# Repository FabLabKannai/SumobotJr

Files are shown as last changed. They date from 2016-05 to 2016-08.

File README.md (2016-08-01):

# Sumobot Jr
Sumobot Jr is open source robot car kit. <br/>
original https://github.com/makenai/sumobot-jr <br/>

## Arduino version
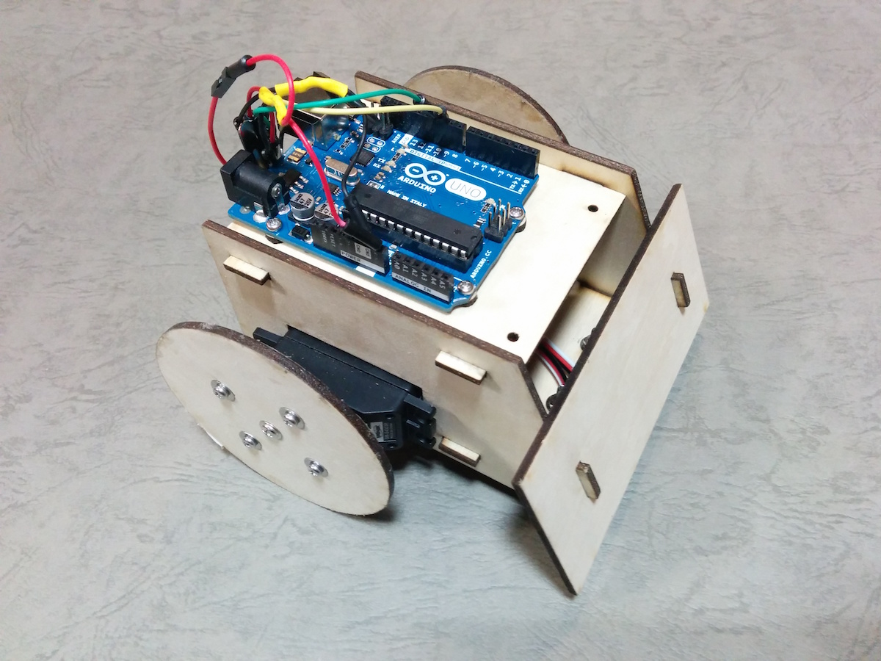
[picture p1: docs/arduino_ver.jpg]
 <br/>
Video [Sumobot Jr](https://www.youtube.com/watch?v=96kZ15I-gVY) <br/>

## Raspberry Pi version
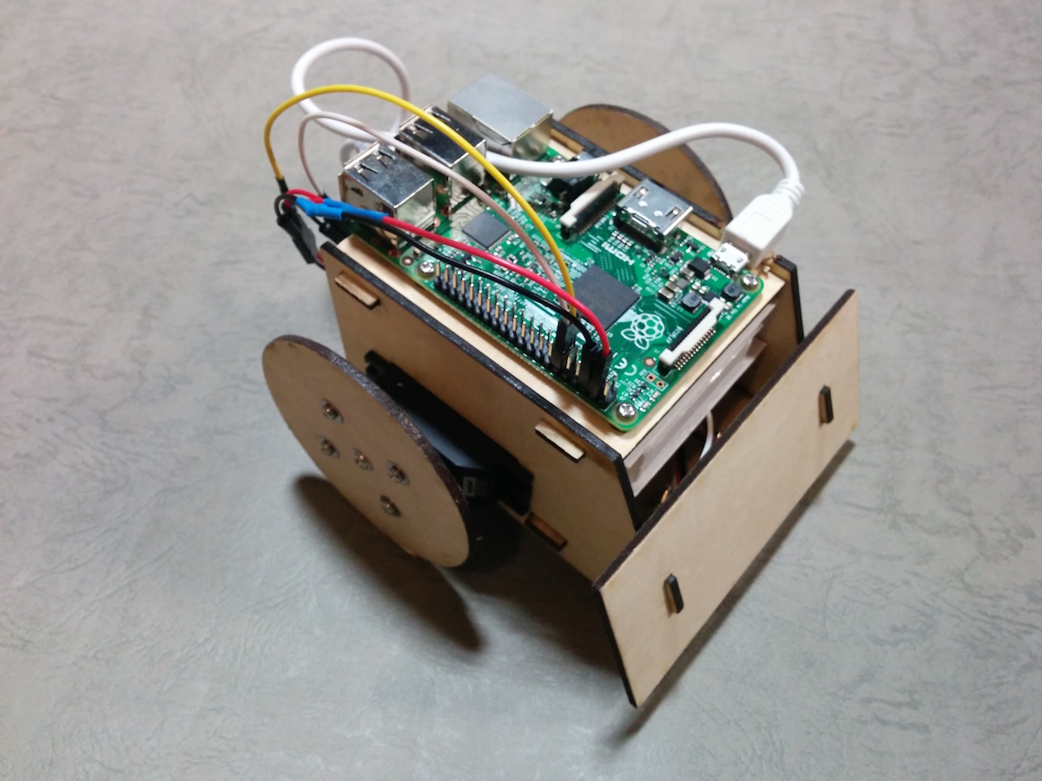
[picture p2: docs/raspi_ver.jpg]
 <br/>
Video [Sumobot with Raspberry Pi](https://www.youtube.com/watch?v=J9WRliGs7vI) <br/>

### Laser Cutter
- Body : SumbotJr 3mm

### 3D Printer
- BallCaster

### Arduino Skech
- sumobot web daemon<br/>
  web app to control Sumobot <br/>
- sumobot turn <br/>
  reft turn <-> stop <-> right turn <br/>
- sumobot command <br/>
  command specify forward, backward or etc
- servo class <br/>
  test using Servo class <br/>
- servo command <br/>
  command to specify the rotation direction and speed <br/>
- servo digitalwrite <br/>
  test using using digitalWrite <br/>
- servo fade <br/>
  clockwide <-> stop <-> anticlockwide <br/>

### Raspberry Pi Prgaram
- Sumobot web <br/>
  Web app to control Sumobot <br/>
- Sumobot Wii <br/>
  Sumobot controlled by Wii Remote <br/>
- Sumobot Scrach <br/>
  Sumobot controlled by Scrach <br/>
- sumobot turn <br/>
  reft turn <-> stop <-> right turn <br/>
- sumobot command <br/>
  command specify forward, backward or etc <br/>
- [WiringPi Servo](https://github.com/FabLabKannai/RaspiStudy/tree/master/4_python/sample/wiringpi_servo) <br/>
  test for Continuous Rotation Servo <br/> 
   
### Docs
- Parts
- Assembly

### Blog (Japanese)
http://android.ohwada.jp/archives/6714

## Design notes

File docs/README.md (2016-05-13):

# Docs - Sumobot Jr

### Arduino version
[see Arduino version](https://github.com/FabLabKannai/SumobotJr/tree/master/docs/arduino/) <br/>
 <br/>

### Raspberry Pi version
[see Raspberry Pi version](https://github.com/FabLabKannai/SumobotJr/tree/master/docs/raspi/) <br>
 <br/>

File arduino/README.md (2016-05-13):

# Arduino Skech - Sumobot Jr

 <br/>

## Skechs
- sumobot turn <br/>
  reft turn <-> stop <-> right turn <br/>
  Video [Sumobot Jr](https://www.youtube.com/watch?v=96kZ15I-gVY) <br/>
- sumobot command <br/>
  command specify forward, backward or etc
- servo class <br/>
  test using Servo class <br/>
- servo command <br/>
  command to specify the rotation direction and speed <br/>
- servo digitalwrite <br/>
  test using digitalWrite <br/>
- servo fade <br/>
  clockwide <-> stop <-> anticlockwide <br/>

### blog (Japanese)
http://android.ohwada.jp/archives/6674

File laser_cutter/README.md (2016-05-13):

# Laser Cutter - Sumobot Jr

- Body : SumbotJr 3mm <br/>
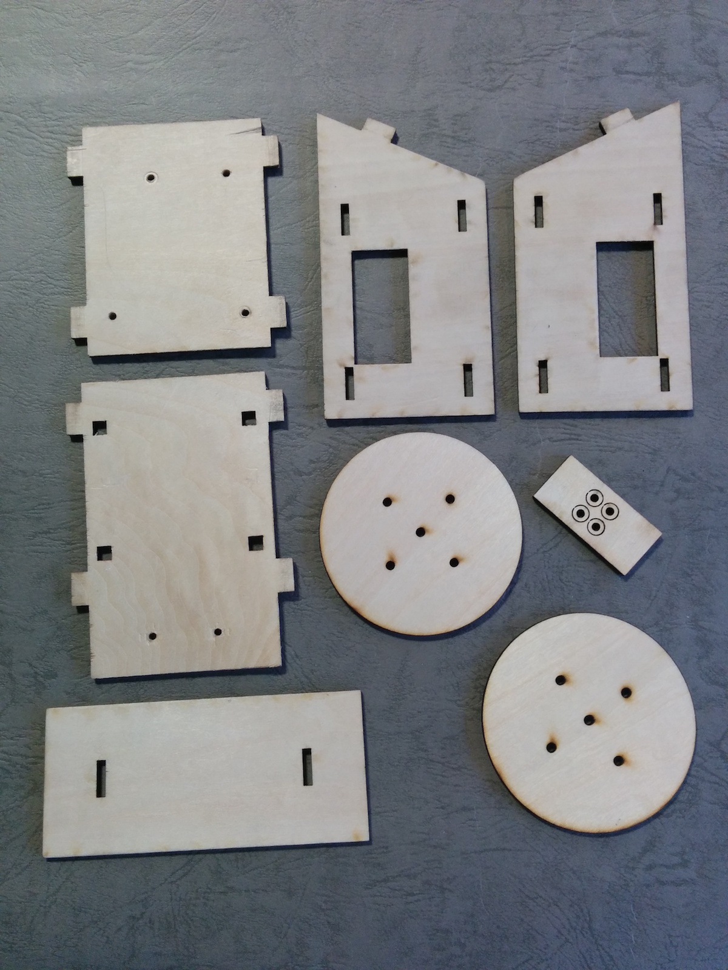
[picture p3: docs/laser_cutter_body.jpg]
 <br/>

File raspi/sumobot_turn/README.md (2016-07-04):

# sumobot turn - RasPi Program

Test for Sumobot using  continuous rotation servos <br/>
 <br/>
Video [Sumobot with Raspberry Pi](https://www.youtube.com/watch?v=J9WRliGs7vI) <br/>

## Program
- sumobot turn <br/>
Sumobot run immediately, when the program is started. <br/>
- sumobot turn check <br/>
Program starts, and it checks the state of the P13(GPIO 27). <br/>
Sumobot run, if pin is high. <br/>
Program stop, and Sumobot is stopped, if pin is low. <br/>

### Behavior
clockwide <-> stop <-> anticlockwide <br/>

### Install
> $ cd /tmp<br/>
$ git clone https://github.com/FabLabKannai/SumobotJr.git <br/>
$ mkdir ~/sumobot/ <br/>
$ cp SumobotJr/raspi/sumobot_turn/sumobot_turn_check.py ~/sumobot/ <br/>

### Start Automatically 1
Set to start this program, when the power is turned on. <br/>
Change /etc/rc.local <br/>
Add one line before "exit 0" <br/>
> $ sudo cp -p /etc/rc.local /etc/rc.local.orig <br/>
$ sudo nano /etc/rc.local <br/>
... <br/>
\# add <br/>
python /home/pi/sumobot/sumobot_turn_check.py <br/>
exit 0  <br/>

### Start Automatically 2
Alternative to change /etc/rc.local <br/>
> $ cd /tmp/SumobotJr/raspi/sumobot_turn/ <br/>
$ sudo cp -p /etc/rc.local /etc/rc.local.orig <br/>
$ sudo cp -f rc.local.sumobot_turn /etc/rc.local <br/>
$ sudo chmod 755 /etc/rc.local <br/>

### Quit to start automatically
Revert to the original /etc/rc.local
> $ sudo cp /etc/rc.local.orig /etc/rc.local

### Hardwear setup
Put a 10k resistor between P13(GPIO 27) and P17(3.3V).  <br/>
Sumobot will run endless. <br/>
Sumobot will be stopped, when connect to P14(GND) in place of the P17(3.3v).   <br/>
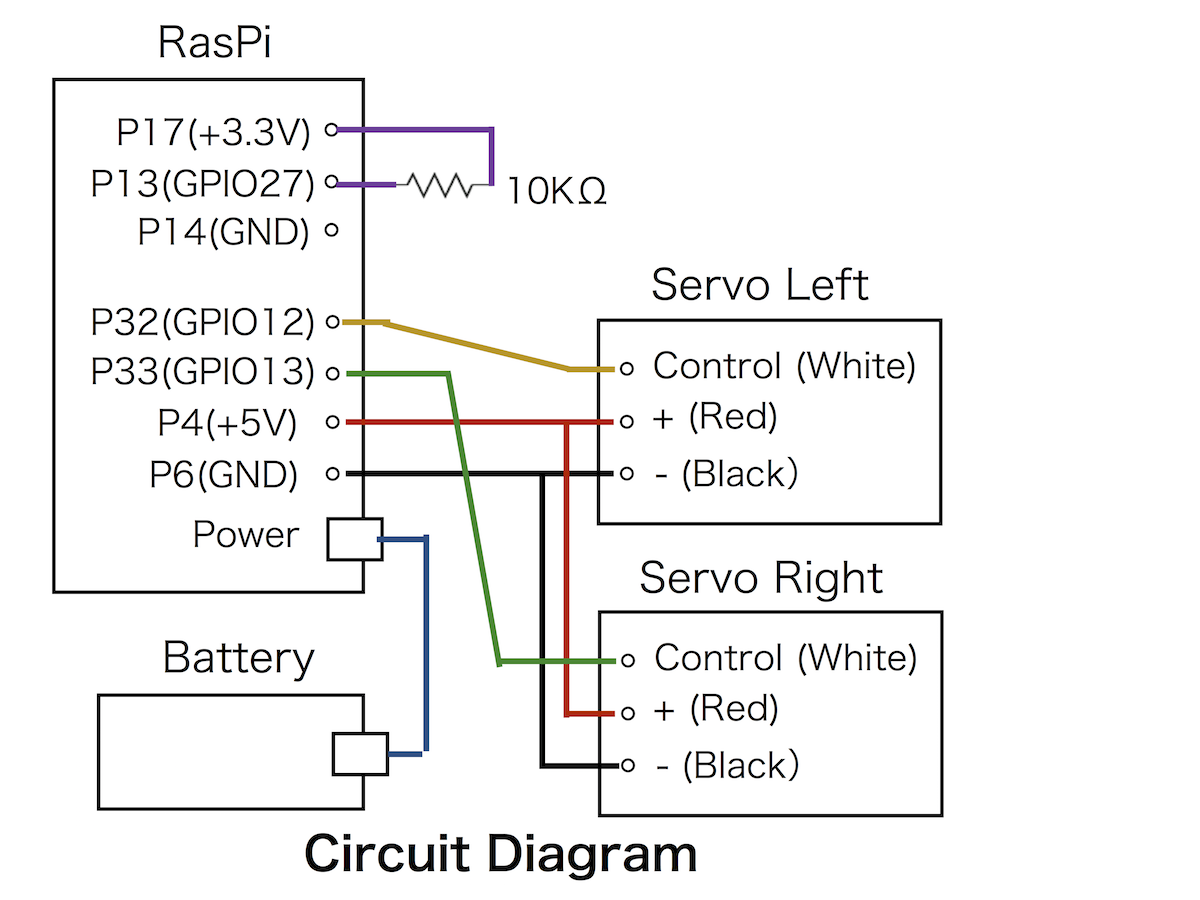
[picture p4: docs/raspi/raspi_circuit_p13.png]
 <br/>

### Blog (Japanese)
http://android.ohwada.jp/archives/6819

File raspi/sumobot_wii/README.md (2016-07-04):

# sumobot wii - RasPi Program

Sumobot controlled by Wii remote <br/>
 <br/>

## Program
- sumobot wii remote <br/>
Sumobot run immediately, when the program is started. <br/>
- sumobot wii remote check <br/>
Program starts, and it checks the state of the P13 (GPIO 27). <br/>
Sumobot run, if pin is low. <br/>
Program stop, and Sumobot is stopped, if pin is high. <br/>

### Install libraly
> $ sudo apt-get install --no-install-recommends bluetooth <br/>
> $ sudo apt-get install python-cwiid <br/>

### Install sumobot wii
> $ cd /tmp <br/>
> $ git clone https://github.com/FabLabKannai/SumobotJr.git <br/> 
> $ mkdir ~/sumobot/ <br/>
> $ cp SumobotJr/raspi/sumobot_wii/sumobot_wii_remote.py ~/sumobot/ <br/>

### Usage

**Connnect** <br/>
RaspberryPi is bootted. <br/>
and after about three minutes, LED will be trun on. <br/>
push 1 and 2, when LED on. <br/>
come to light vibration, when connect wii remote to RaspberryPi. <br/>

**Quit** <br/>
push +(plus) and -(minus) <br/>

**Control** <br/>
the arrow keys  <br/>
- up : forward <br/>
- down : backward <br/>
- left : turn left <br/>
- right : turn right <br/>

- -(minus) : LED off <br/>
- +(plus) : LED on <br/>
- 1 : LED blink <br/>
- others : nothing <br/>

### Start Automatically 1
Set to start this program, when the power is turned on. <br/>
Change /etc/rc.local <br/>
Add one line before "exit 0" <br/>
> $ sudo cp -p /etc/rc.local /etc/rc.local.orig <br/>
$ sudo nano /etc/rc.local <br/>
... <br/>
\# add <br/>
python /home/pi/sumobot/sumobot_wii_remote.py & <br/>
exit 0  <br/>

### Start Automatically 2
Alternative to change /etc/rc.local <br/>
> $ cd /tmp/SumobotJr/raspi/sumobot_wii/  <br/> 
$ sudo cp -p /etc/rc.local /etc/rc.local.orig   <br/>
$ sudo cp -f rc.local.sumobot_wii /etc/rc.local   <br/>
$ sudo chmod 755 /etc/rc.local   <br/>

### Hardwear setup
Put LED and a 330 ohms resistor between P11(GPIO 17) and P9(GND).  <br/>
Put a 10k ohms resistor between P13(GPIO 27) and P14(GND).  <br/>
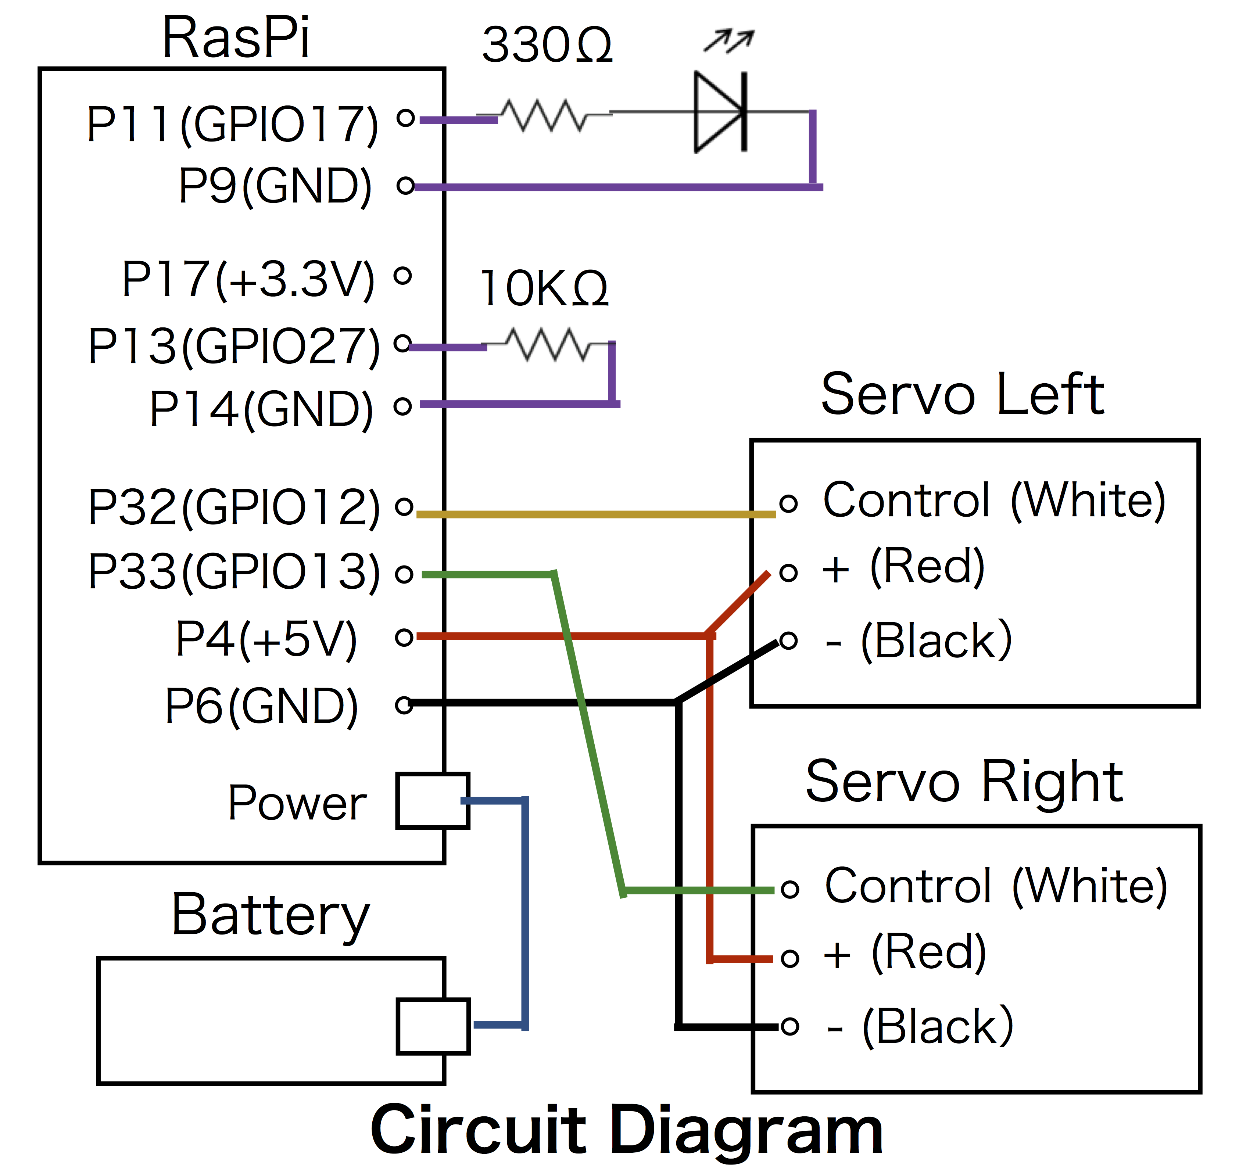
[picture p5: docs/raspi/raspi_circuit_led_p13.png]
 <br/>

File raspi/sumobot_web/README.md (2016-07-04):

# sumobot web - Raspberry Pi Prgaram

 <br/>

## Sumobot Web
- Sumobot Web Sample 1 <br/>
  Web app to control Sumobot <br/>

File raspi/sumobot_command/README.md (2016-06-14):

# sumobot command - RasPi Program

Test for Sumobot using  continuous rotation servos <br/>
 <br/>

### Usage
command format : one ASCII charactor <br/>
- w : wakeup <br/>
- q : quit <br/>
- 0 : LED Off <br/>
- 1 : LED On <br/>
- 2 : LED Blink <br/>
- f : forward <br/>
- b : backward <br/>
- l : left turn <br/>
- r : right turn <br/>
- othes : stop <br/>

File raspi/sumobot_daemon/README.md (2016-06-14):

# sumobot deamon - Raspberry Pi Prgaram

 <br/>

## Prgarams
- Sumobot Web Sample 1 <br/>
  web app to control Sumobot with button <br/>

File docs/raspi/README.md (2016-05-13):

# Raspberry Pi version - Sumobot Jr

This document for Raspberry Pi version <br>
[see Arduino version](https://github.com/FabLabKannai/SumobotJr/tree/master/docs/arduino/)

 <br/>
Video [20160501 Sumobot Jr](https://www.youtube.com/watch?v=J9WRliGs7vI) <br/>

## Parts
- [Raspberry Pi 2 B](https://www.switch-science.com/catalog/2127/)
- Continuous servo [SM-S4303R](https://www.pololu.com/product/1248) x 2
- [Portable battery charger](https://www.switch-science.com/catalog/2618/)
- Screws and Nuts : M2.6x10mm x 12、M2.6x15mm x 2
- Zip tie x 2
- Thick rubber band x 2
- Some wire or leads <br>

## Laser Cutter
- Body 3mm - same as Arduino version<br>
 <br/>

## 3D Printer
- BallCaster - same as Arduino version <br>
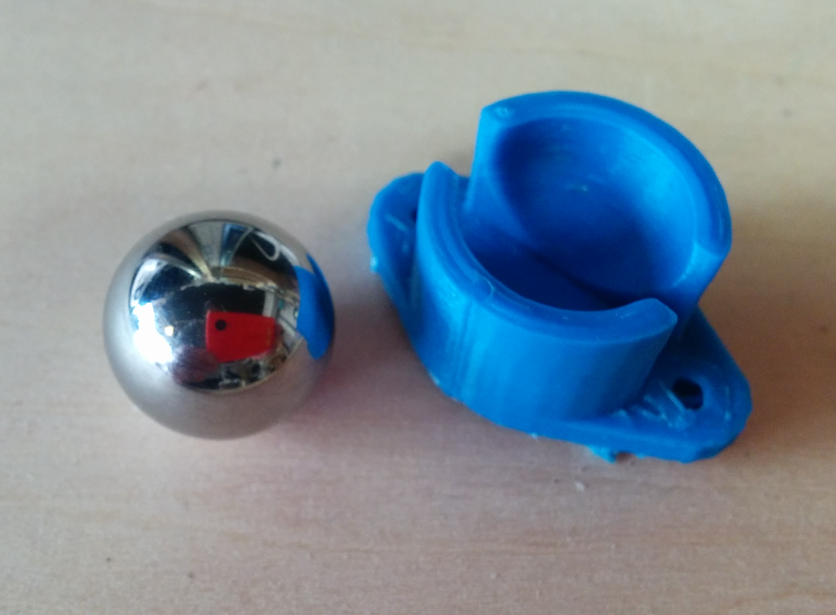
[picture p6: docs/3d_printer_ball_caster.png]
<br/>

## Assembly
Assembly is almost the same as the Arduino version. <br/>
The difference is that to fix Raspberry Pi to the upper plate. <br/>
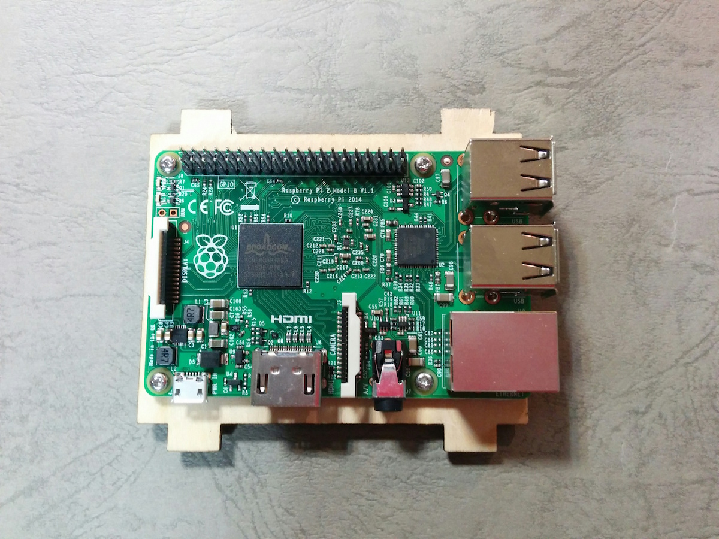
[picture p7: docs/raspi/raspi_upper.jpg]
 <br/>

### Wiring
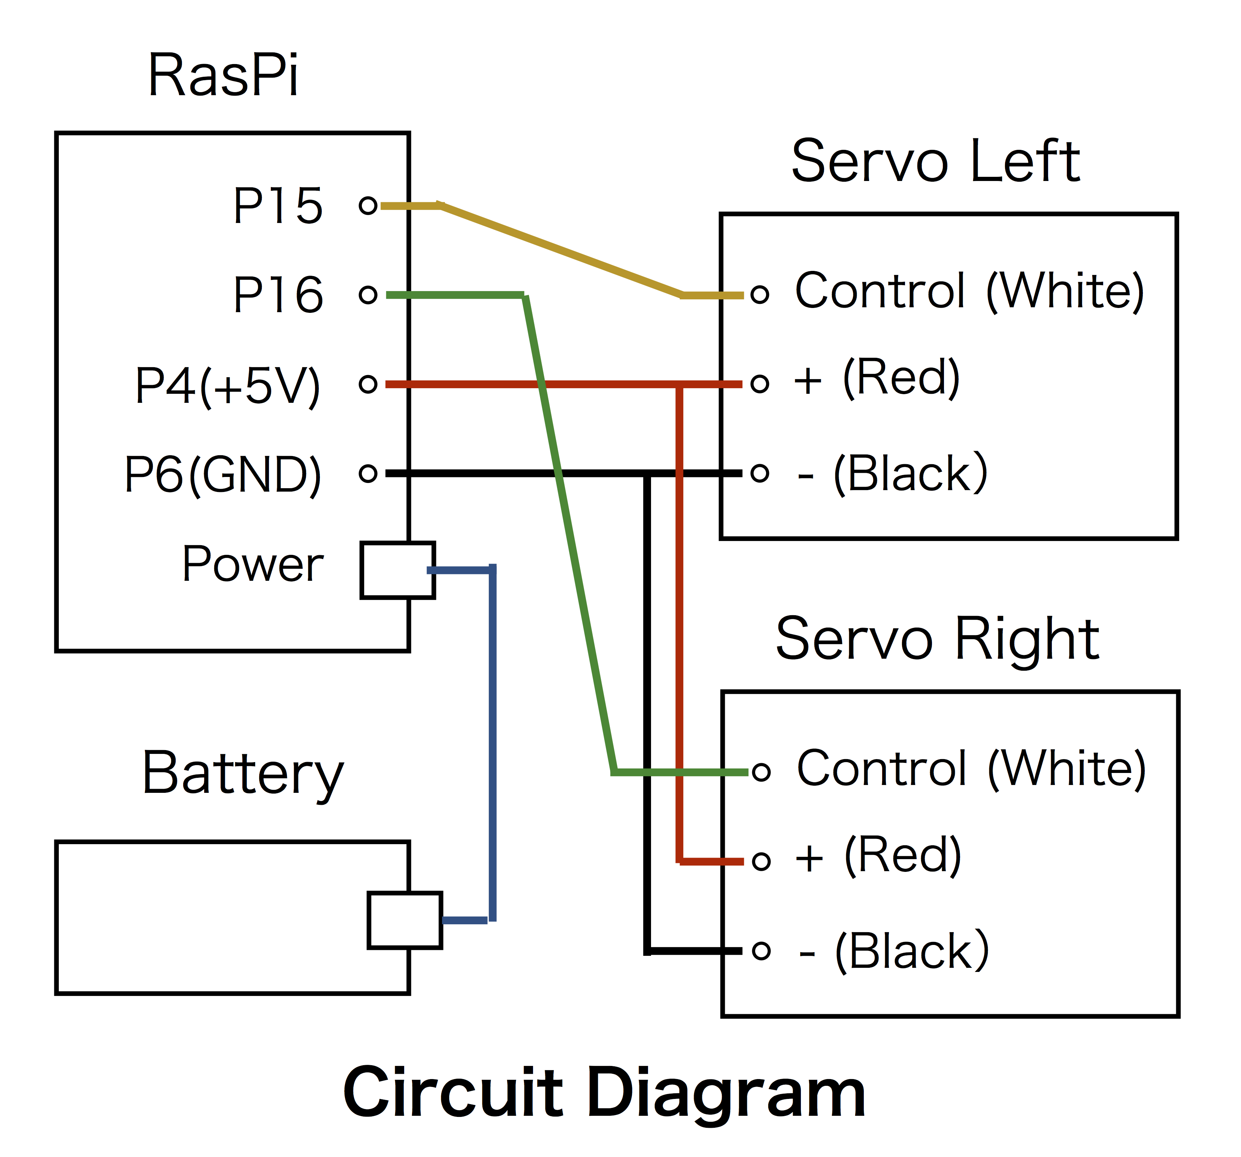
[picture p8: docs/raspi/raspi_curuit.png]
 <br/>

(1) Make a jumper line of male 2 connectors and female single connector. <br/>
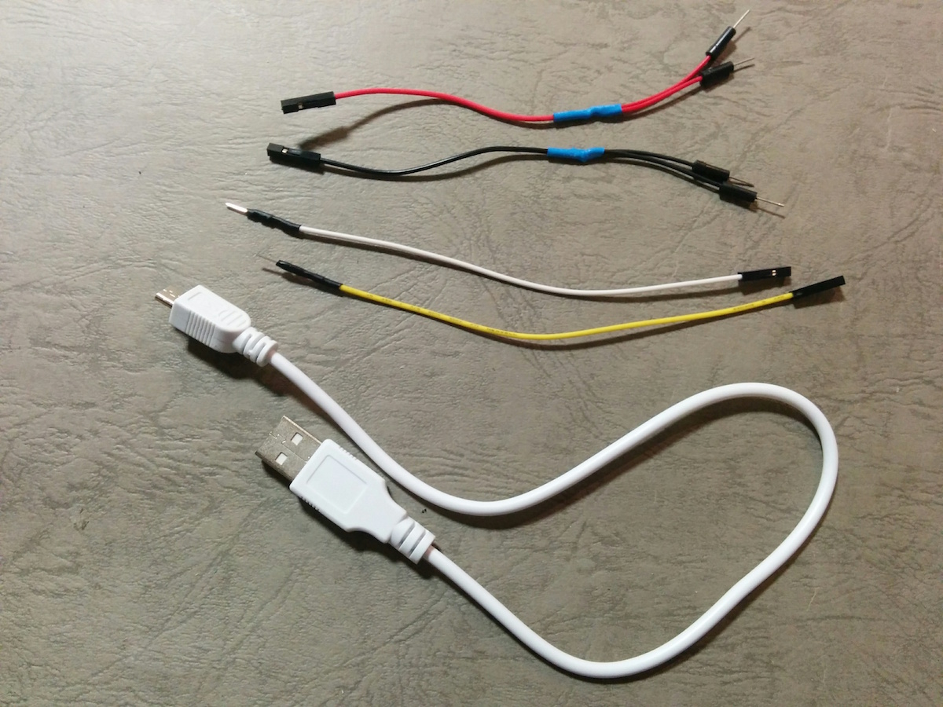
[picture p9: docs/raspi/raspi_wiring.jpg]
 <br/>

(2) Put on the portable battery charger on the body .<br/>
it is good to to put cardboards at the top and bottom of the portable battery charger.<br/>
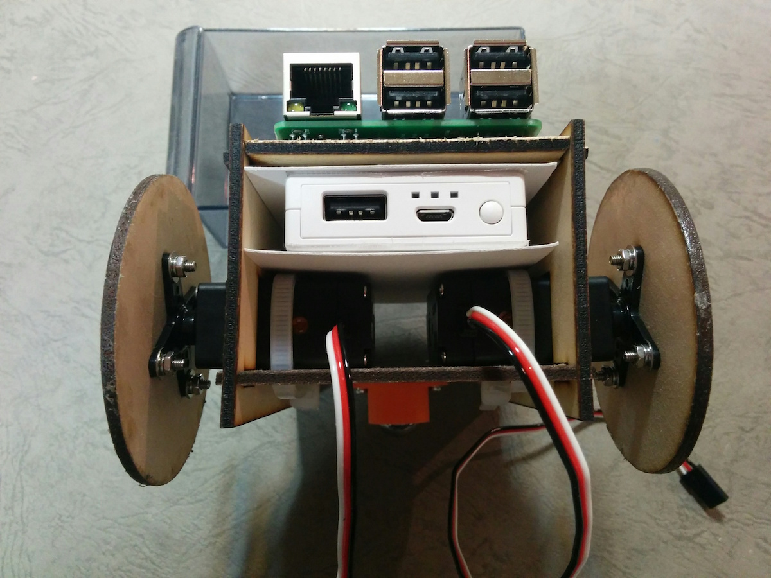
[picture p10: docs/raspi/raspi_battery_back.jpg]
 <br/>

(3) Connect two servos to Raspberry Pi. <br/>
And connect the portable battery charger to Raspberry Pi <br/>
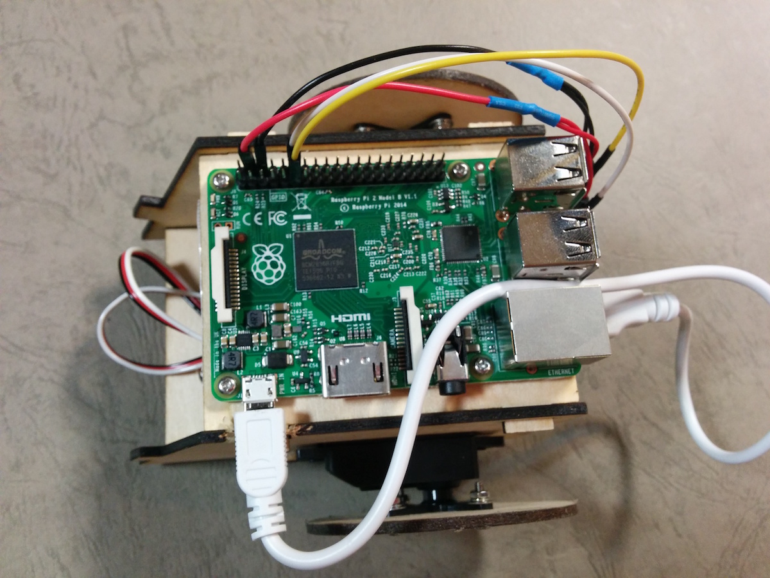
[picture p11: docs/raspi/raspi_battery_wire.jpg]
 <br/>

## Program
Set the program [sumobot turn](https://github.com/FabLabKannai/SumobotJr/tree/master/raspi/sumobot_turn) to Raspberry Pi.<br/>
Turn on the power.<br/>
Sumobot is repeating the left turn and right turn. <br/>
like video [20160501 Sumobot Jr](https://www.youtube.com/watch?v=J9WRliGs7vI) <br/>

## ToDo
The spacer is NOT enough 3mm thick. <br/>
Need about 10mm thick. <br/>

- The board of Raspberry Pi is bending, to fix Raspberry Pi to the upper plate, becase the connector pin is long. <br/>
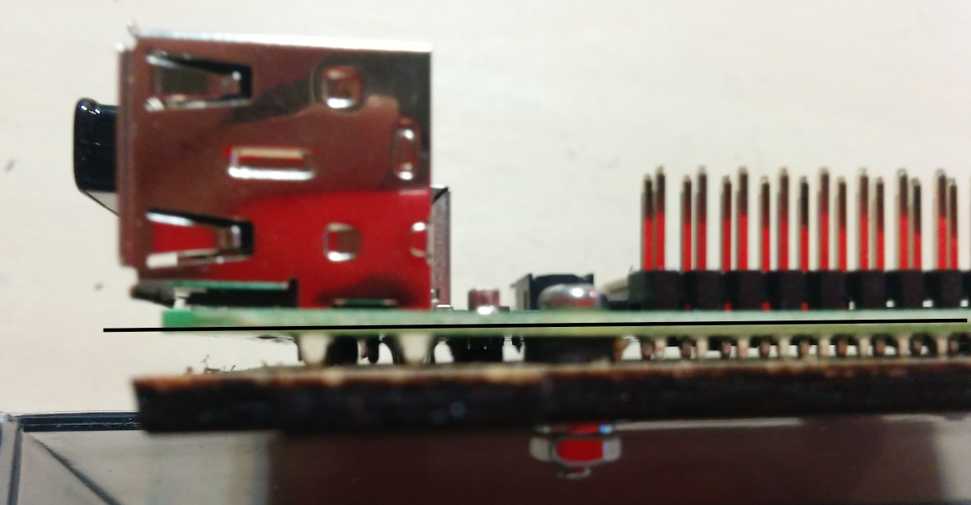
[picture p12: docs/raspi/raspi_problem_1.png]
 <br/>

- Can NOT insert the battery cable to Raspberry Pi, becase the side plate is in the way. <br/>
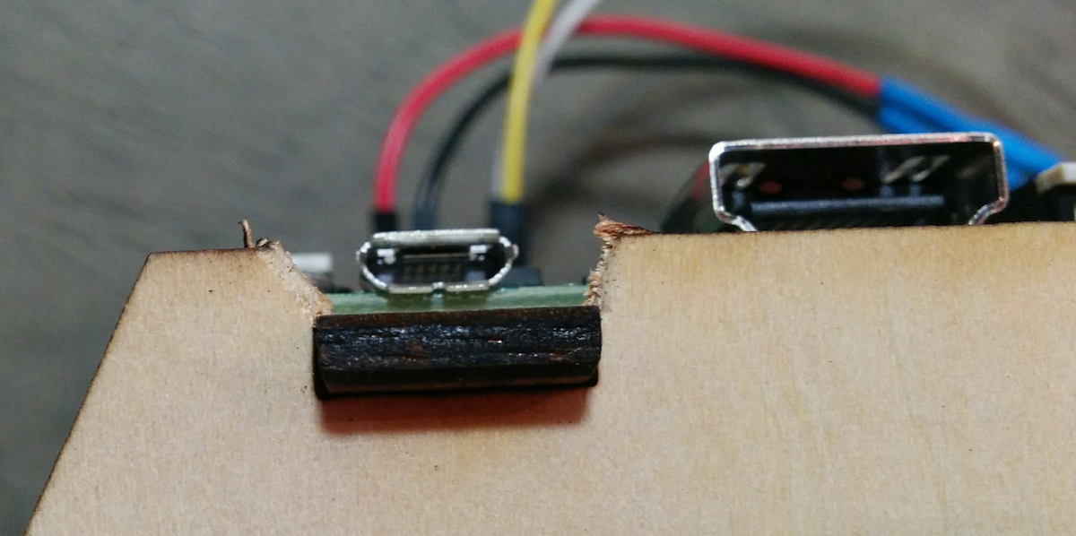
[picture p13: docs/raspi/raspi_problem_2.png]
 <br/>

### Blog (Japanese)
http://android.ohwada.jp/archives/6789

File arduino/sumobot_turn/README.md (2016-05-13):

# sumobot turn - Arduino Skech 

Test for Sumobot using continuous rotation servos <br>
 <br/>
Video [Sumobot Jr](https://www.youtube.com/watch?v=96kZ15I-gVY) <br/>

### Behavior
reft turn <-> stop <-> right turn <br/>

### blog (Japanese)
http://android.ohwada.jp/archives/6714

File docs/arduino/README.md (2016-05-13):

# Arduino version - Sumobot Jr

This document for Arduino version <br>
[see Raspberry Pi version](https://github.com/FabLabKannai/SumobotJr/tree/master/docs/raspi/) <br>

 <br/>
Video [Sumobot Jr](https://www.youtube.com/watch?v=96kZ15I-gVY) <br/>

## Parts
- [Arduino Uno](http://akizukidenshi.com/catalog/g/gM-07385/)
- Continuous servo [SM-S4303R](https://www.pololu.com/product/1248) x 2
- [4 AA Battery holder](http://akizukidenshi.com/catalog/g/gP-04103/)
- AA Battery x 4
- [16mm ball bearing](http://ihc.monotaro.com/item/C38448155/)
- Screws and Nuts : M2.6x10mm x 12、M2.6x15mm x 2
- Zip tie x 2
- Thick rubber band x 2
- Some wire or leads <br>
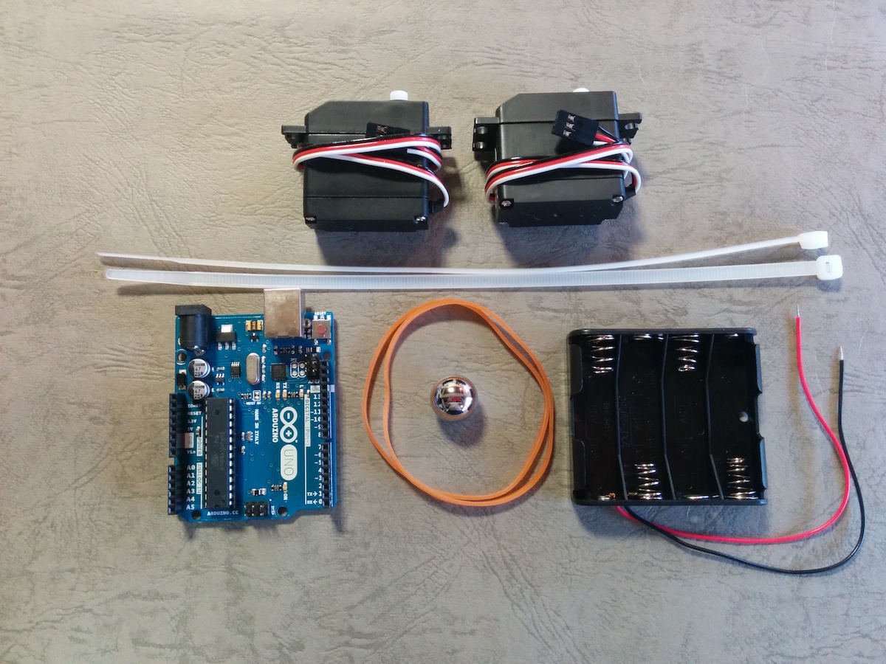
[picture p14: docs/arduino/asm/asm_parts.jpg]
 <br/>

## Laser Cutter
- Body 3mm <br>
 <br/>

## 3D Printer
- BallCaster <br>
<br/>

## Assembly
Video: [Sumobot Jr Assembly video for Nodebots Day 7/27](https://www.youtube.com/watch?v=0Q3hrKUwxDM)

(1) Enlarge the screw holes of the ball caster <br/>
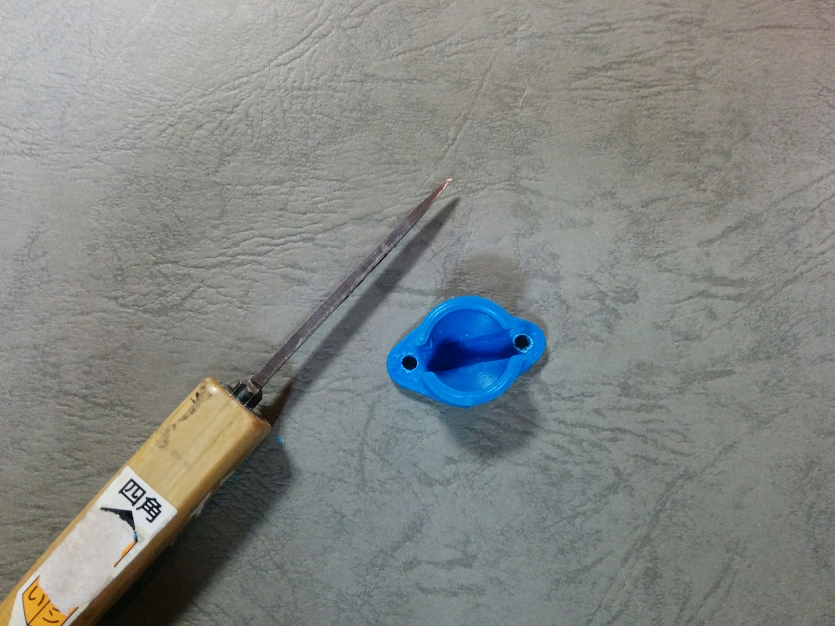
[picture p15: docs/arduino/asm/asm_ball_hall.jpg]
 <br/>

(2) Screw the ball caster on the bottom plate <br/>
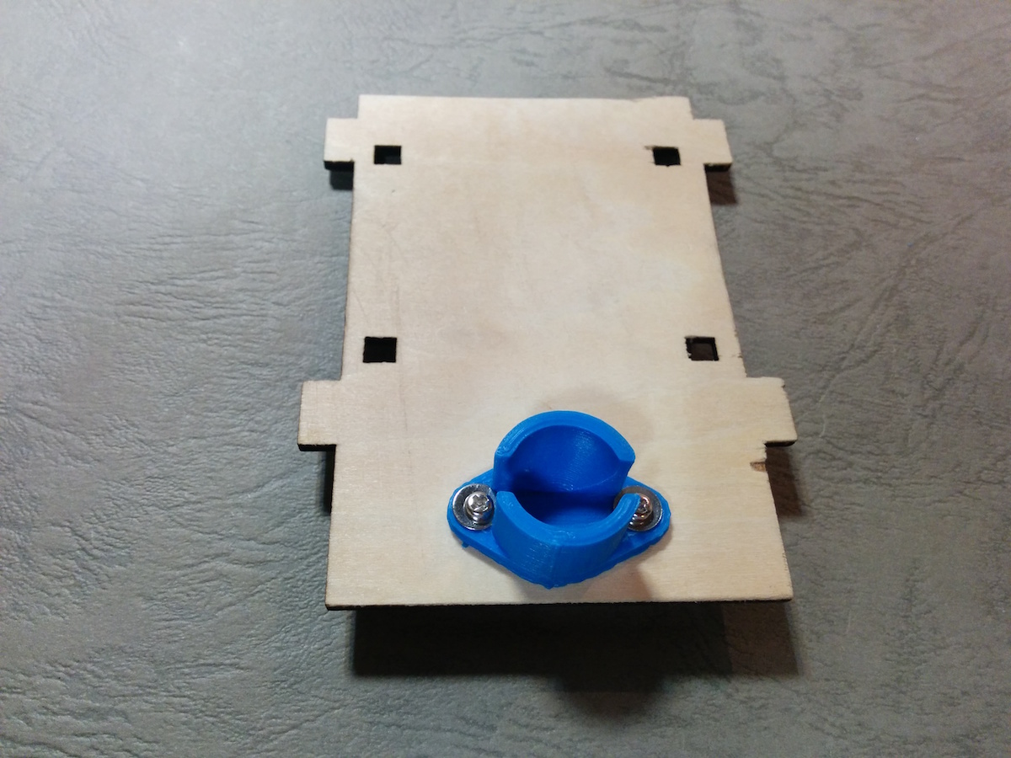
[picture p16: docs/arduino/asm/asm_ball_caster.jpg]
 <br/>

(3) Enlarge the screw holes of the servo horns <br/>
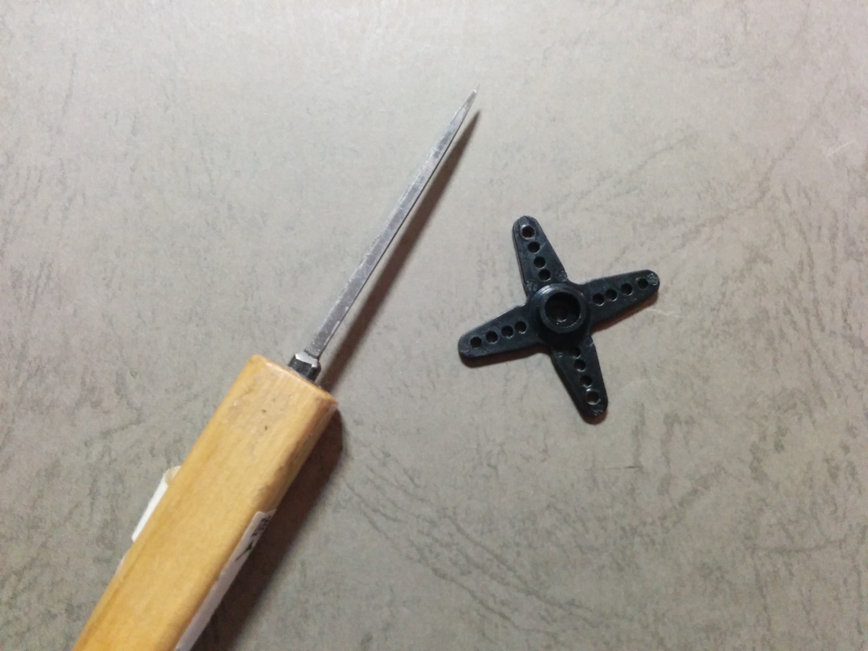
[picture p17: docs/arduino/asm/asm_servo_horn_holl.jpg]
 <br/>

(4) Screw the servo horns on the wheels <br/>
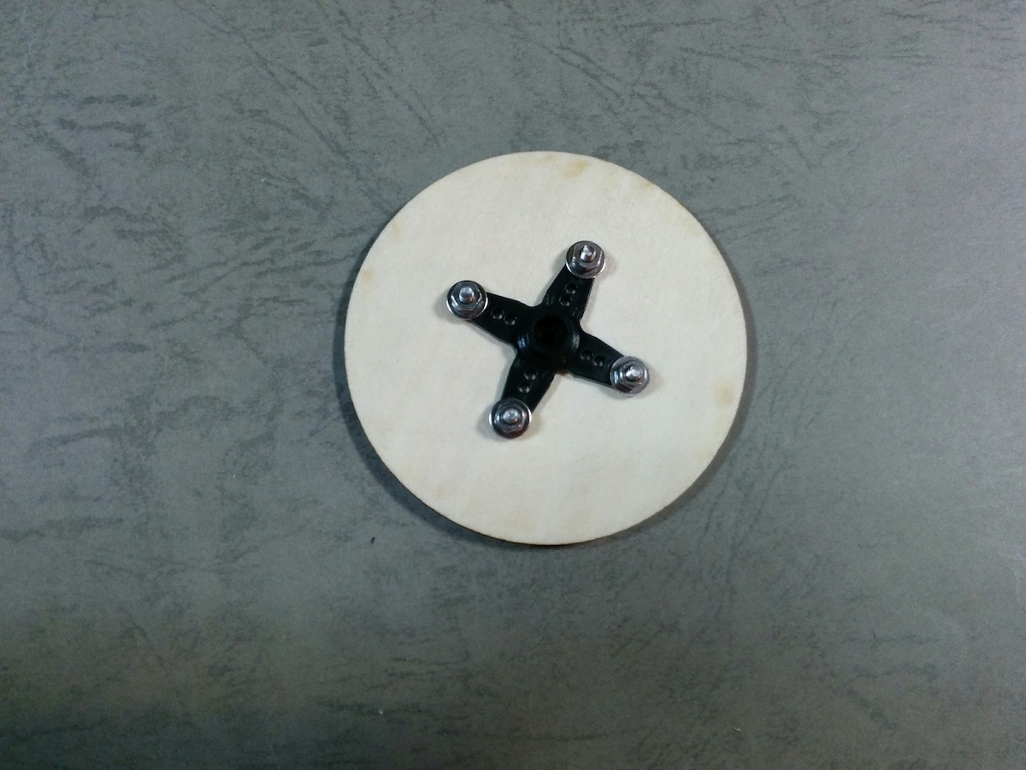
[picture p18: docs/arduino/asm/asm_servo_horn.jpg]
 <br/>

(5) Fix the servos on the bottom plate with zip ties <br/>
 <br/>

(6) Screw Arduino on the top plate <br/>
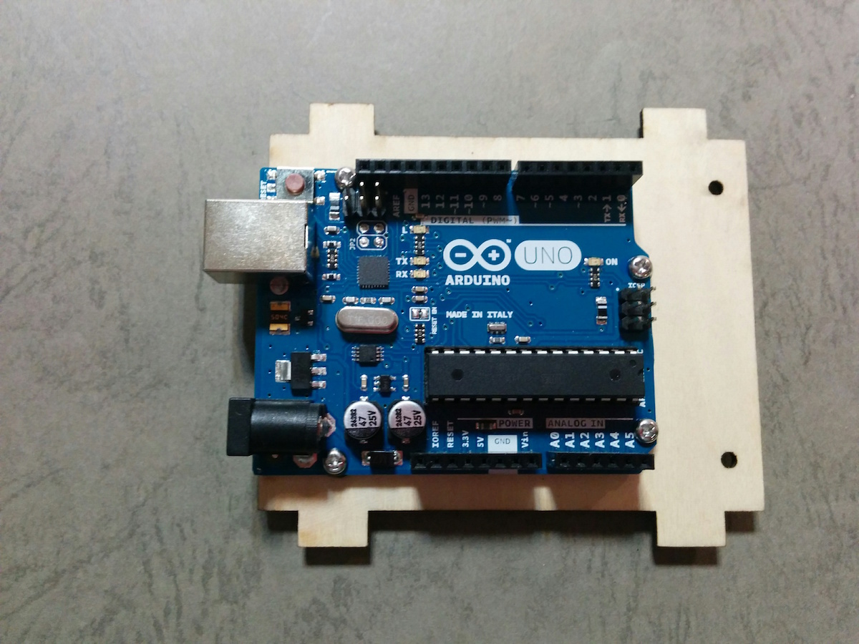
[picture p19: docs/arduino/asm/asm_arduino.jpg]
 <br/>

(7) Attach the top plate on the body <br/> 
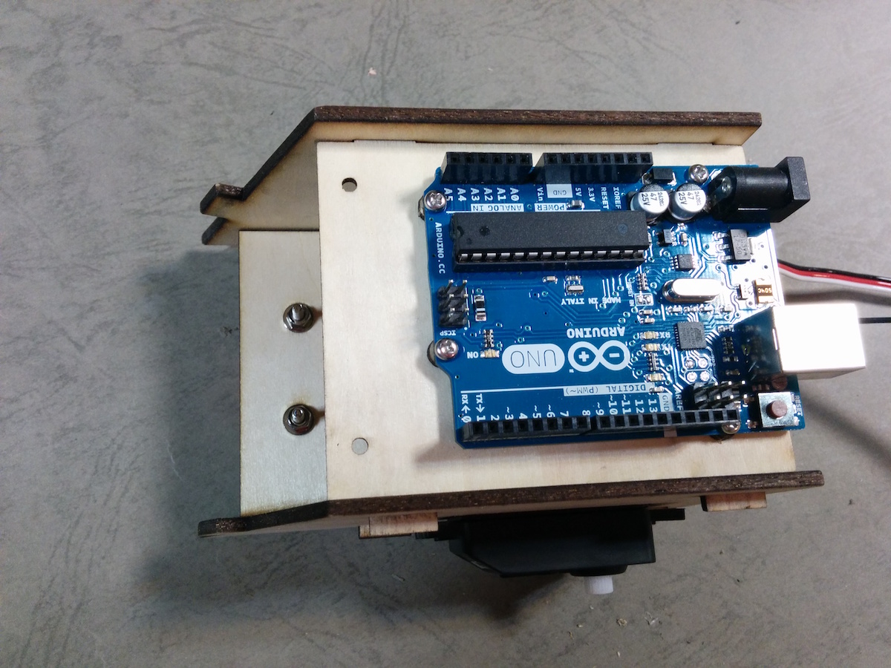
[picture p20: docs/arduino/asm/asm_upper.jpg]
 <br/>

(8) Screw the wheels on the body <br/>
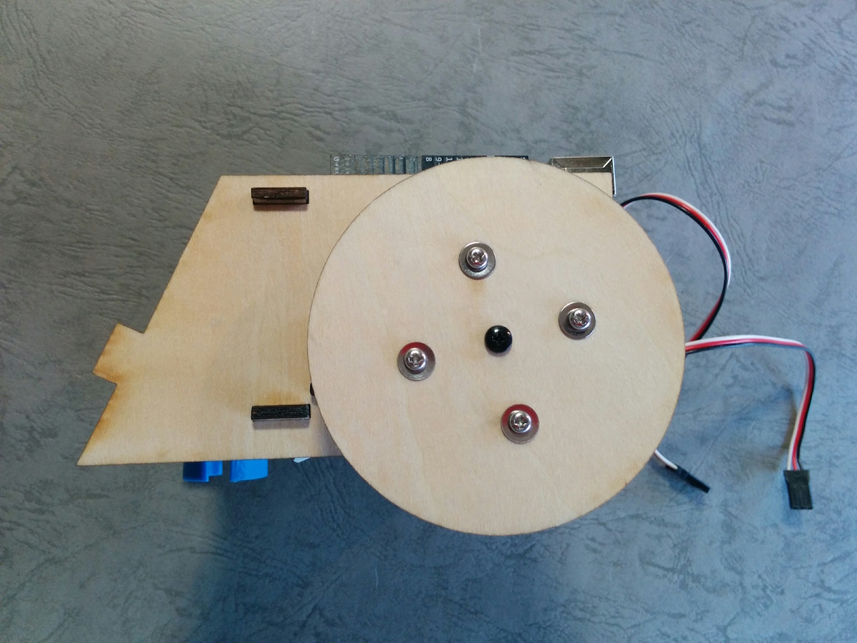
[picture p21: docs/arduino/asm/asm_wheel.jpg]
 <br/>

(9) Attach the front plate on the body <br/>
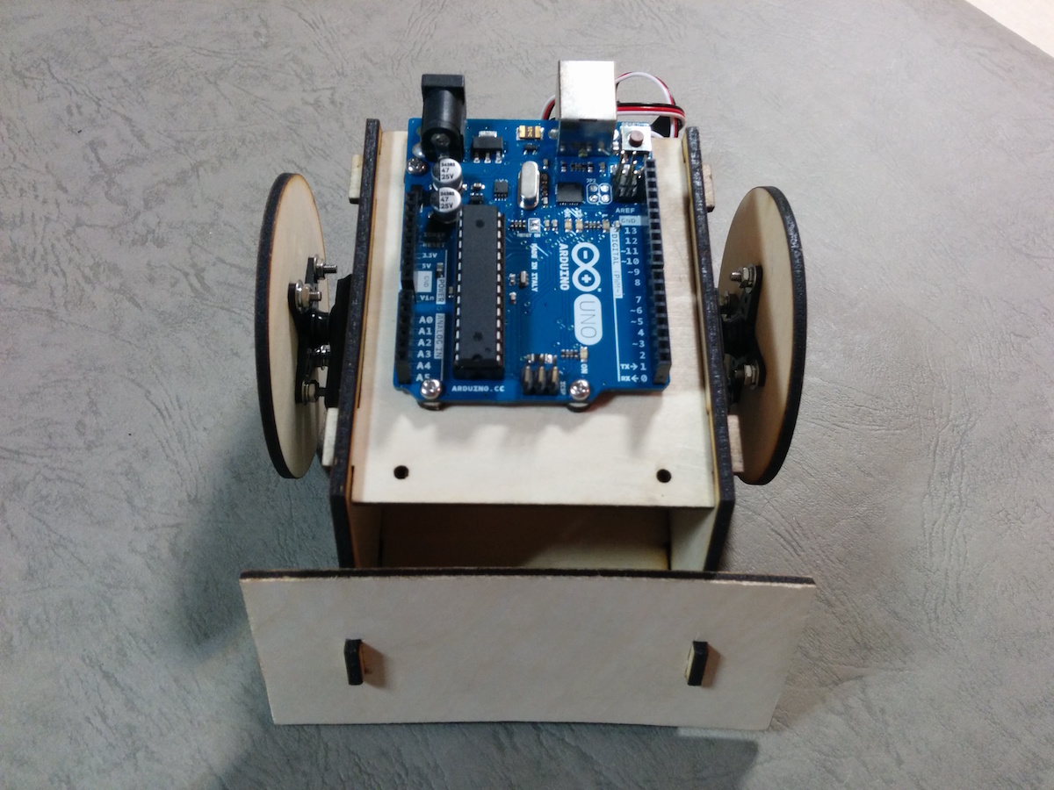
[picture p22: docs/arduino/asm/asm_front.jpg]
 <br/>

(10) Fit the ball on the ball caster <br/>
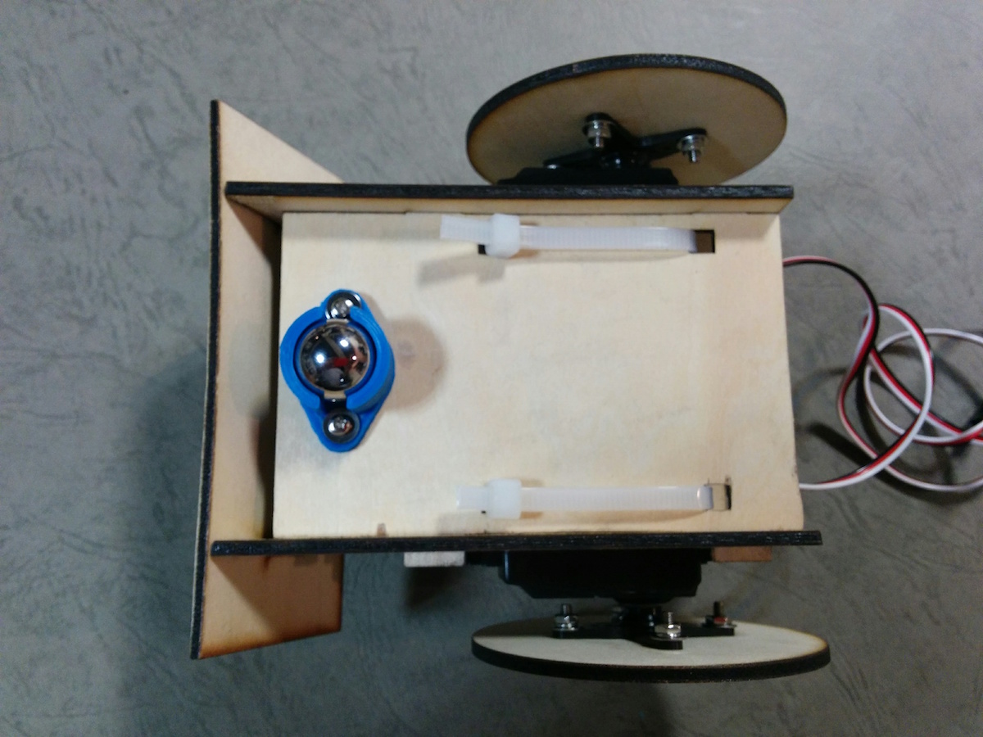
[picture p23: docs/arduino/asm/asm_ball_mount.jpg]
 <br/>

### Wiring
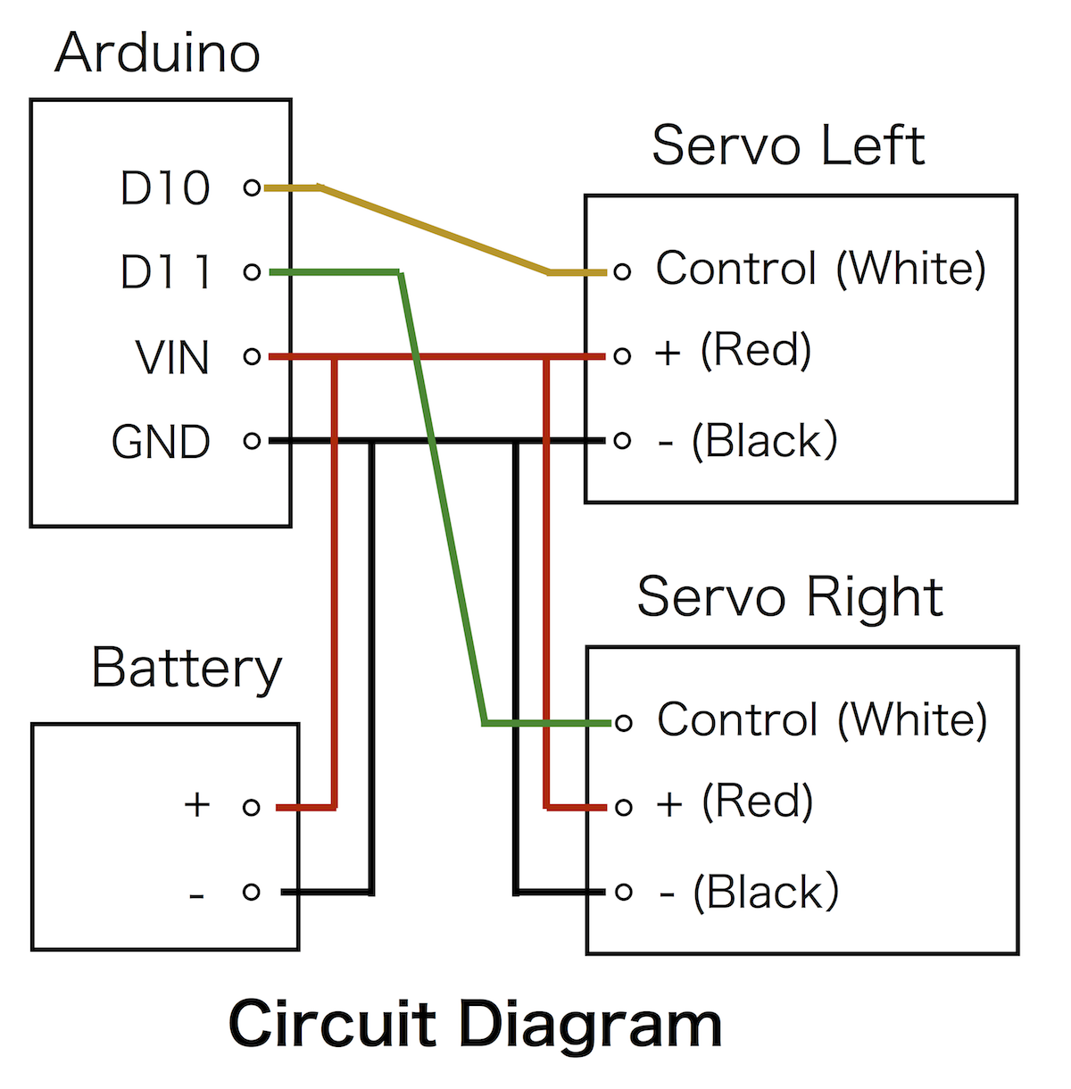
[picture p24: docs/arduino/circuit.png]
 <br/>

(11) Solder the jumper wires to the battery holder <br/>
(12) Solder the jumper wires with four connectors <br/>
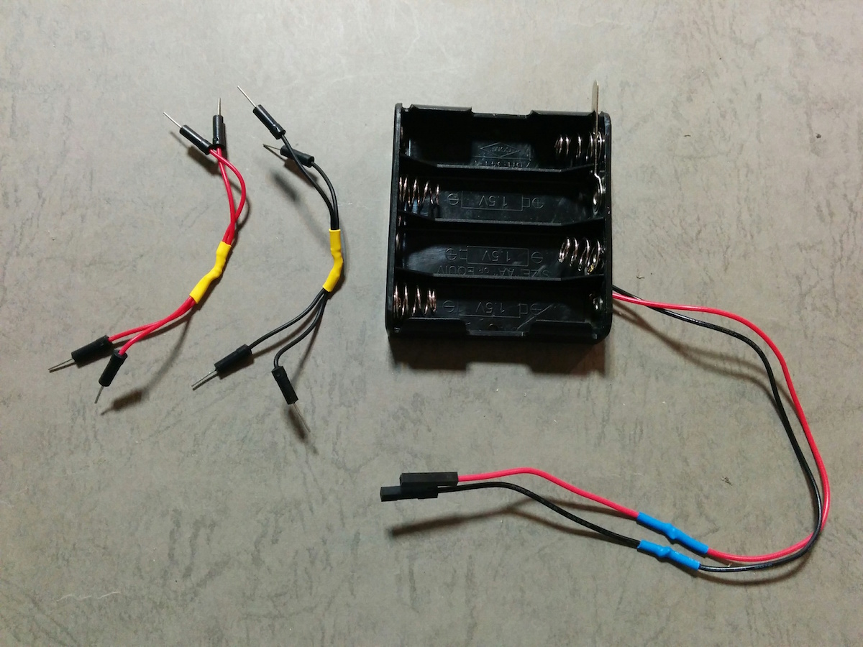
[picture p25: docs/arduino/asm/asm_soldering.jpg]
 <br/>

(13) Connect the battery holder and two servos to Arduino <br/>
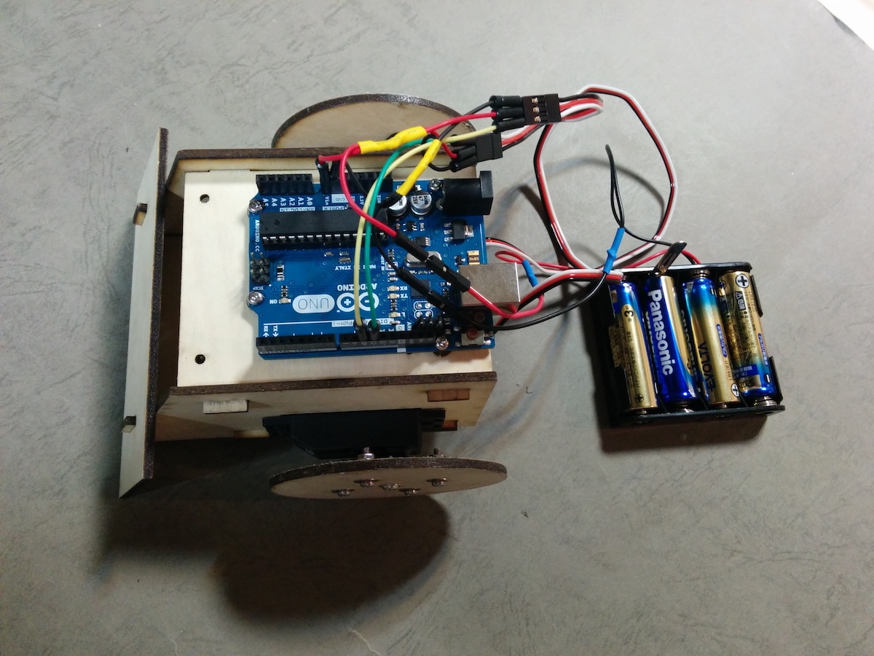
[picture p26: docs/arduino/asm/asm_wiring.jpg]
 <br/>

(14) Put on the battery holder on the body .<br/>
it is good to to put cardboards at the top and bottom of the battery holder.<br/>
 <br/>

(15) It is completed. <br/>
 <br/>

## Program
Set the skech [sumobot turn](https://github.com/FabLabKannai/SumobotJr/tree/master/arduino/sumobot_turn) to Arduino.<br/>
Turn on the power.<br/>
Sumobot is repeating the left turn and right turn. <br/>
like video [Sumobot Jr](https://www.youtube.com/watch?v=96kZ15I-gVY) <br/> <br/>

## ToDo
- How to fix the rubber band to the wheel <br/>
It is eazy to remove the rubber band from the wheel <br/>
 <br/>

### Blog (Japanese)
http://android.ohwada.jp/archives/6714

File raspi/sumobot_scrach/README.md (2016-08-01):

# sumobot scrach - RasPi Program

Sumobot controlled by Scrach <br/>
 <br/>

## Program
Scratch :send broadcast message, when click the image <br/>
Python : receive broadcast message, and move sumobot <br/>

Correspondence of image and message.
- forward : "f"
- backward : "b"
- left : "l"
- right : "r"
- stop : "s"

### Requrement
- [py-scratch](https://code.google.com/archive/p/py-scratch/)

### Setup
copy "sumobot.sb" under directory /home/pi/Scrach/ <br/>
copy "sumobot_scrach.py" under directory /home/pi/sumobot/ <br/>

### Usage
(1) connect to Raspberry Pi (Sumobot) using VNC <br/>

(2) start Scrach <br/>
(3) open file <br/>
file -> open -> sumobot.sb <br/>

(4) start terminal <br/> 
(5) excute python code <br/> 
> cd ~/sumobot/ <br/> 
sudo python sumobot_scrach.py <br/> 

(6) click image on Scrach

### Blog (Japanese)
http://android.ohwada.jp/archives/7152

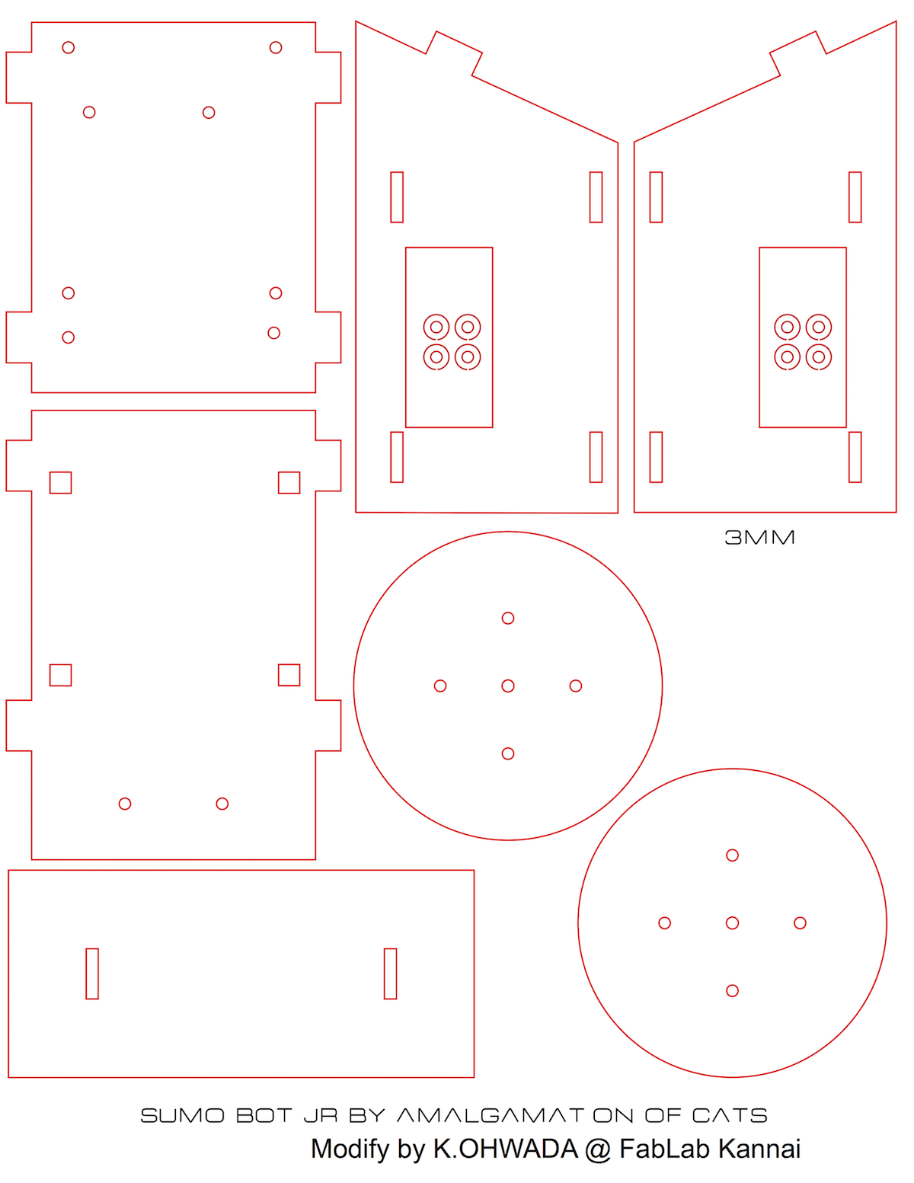
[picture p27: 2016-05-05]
docs/sumbotjr_3mm_custom_ai.png

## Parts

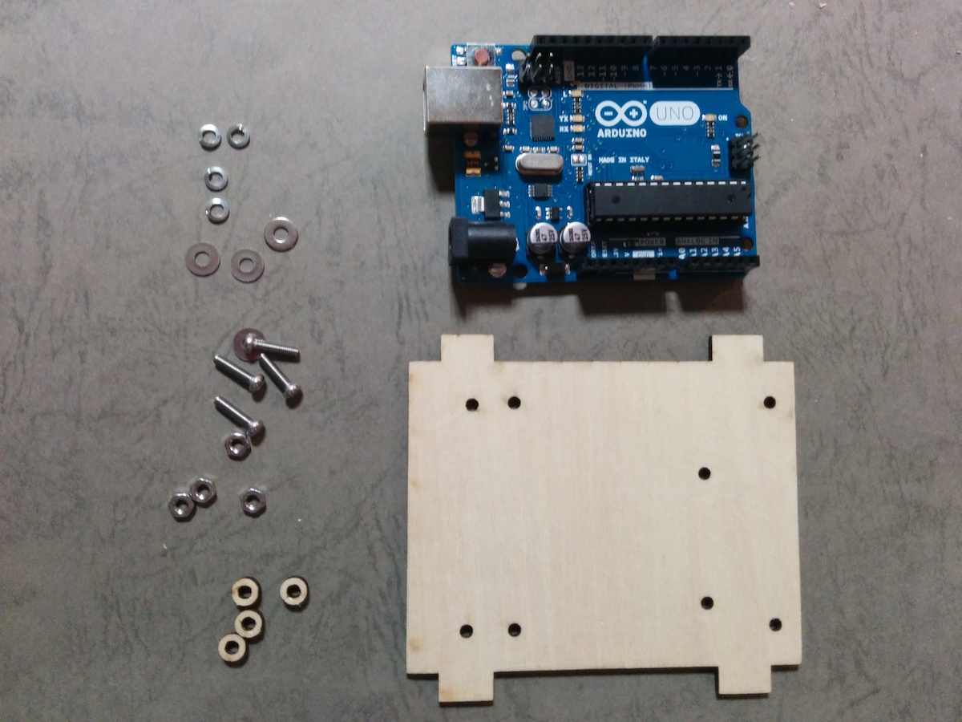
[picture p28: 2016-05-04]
docs/arduino/asm/asm_arduino_parts.jpg

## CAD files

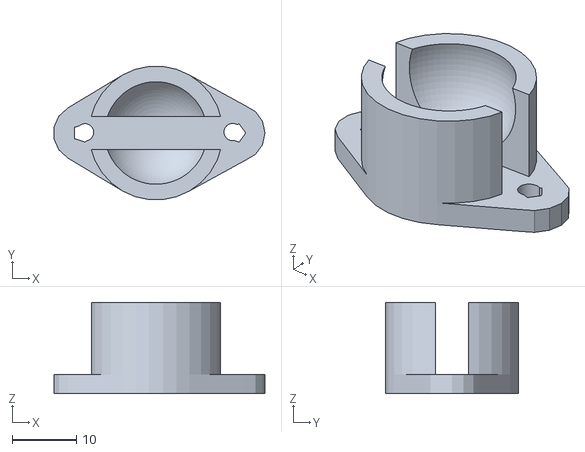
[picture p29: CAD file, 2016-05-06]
3d_printer/ball_caster/BallCaster-custom.stl
32.9 x 20.8 x 14.3

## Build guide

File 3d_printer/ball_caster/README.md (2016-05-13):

# BallCaster - 3D Printer

- BallCaster <br/>
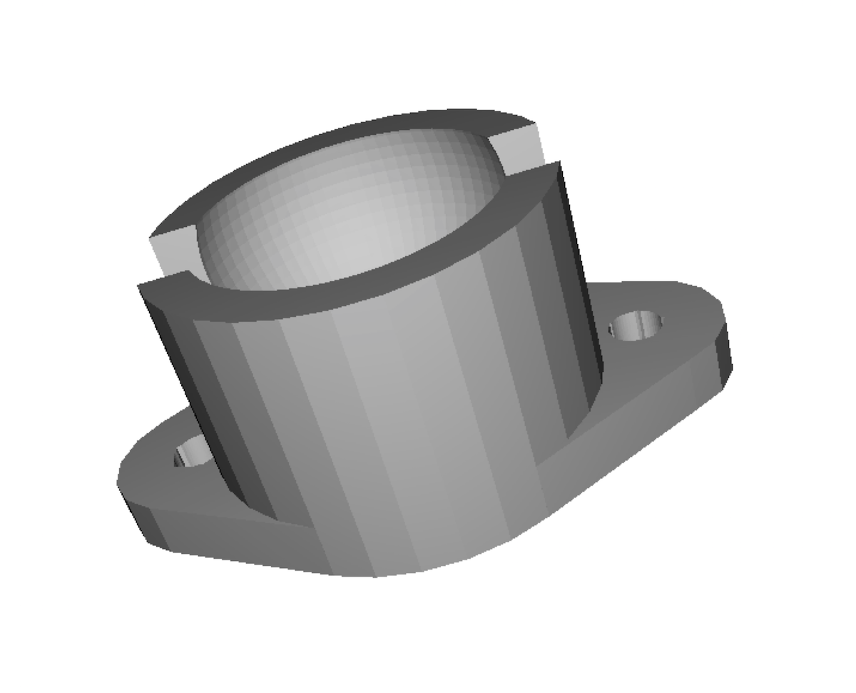
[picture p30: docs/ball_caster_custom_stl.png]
  <br/>

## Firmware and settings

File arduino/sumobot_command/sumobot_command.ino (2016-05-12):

// Sumobot Command
// 2016-04-20 K.OHWADA

// Usage
// command format : one ASCII charactor
//   0 : LED off
//   1 : LED on
//   2 : LED bilnk
//    f : forward
//    b : backward
//    l : left turn
//    r : right turn
//   othes : stop

// Servo
// SpringRC SM-S4303R
// 0 : clokckwide full-speed
// 90 : stop
// 180 : anticlokckwide full-speed

// Bluetooth module
// Microchip RN-42 Bluetooth Evaluation Kit

// Note
// AltSoftSerial is be NOT used
// Because ISR (Interrupt Signal Register) are colliding with Servo class
// Error message : multiple definition of `__vector_11'

#include <SoftwareSerial.h>
#include <Servo.h> 

// Pin
#define P_BT_RST      2
#define P_BT_RX        8
#define P_BT_TX        9
#define P_SERVO_L  10 
#define P_SERVO_R  11
#define P_LED          13

// Serial
#define SERIAL_SPEED  9600 
#define BT_SPEED  115200

SoftwareSerial softSerial(P_BT_RX, P_BT_TX);
Servo servo_l, servo_r;

int cnt = 0;
boolean isRun = false;
boolean isLed = false;
boolean isBlink = true;

// setup
void setup() {
    // serial
    Serial.begin(SERIAL_SPEED);
    Serial.println("Start sumobot command"); 
    Serial.println("exsample 'f' for forward"); 
    softSerial.begin(BT_SPEED);
    // servo
    servo_l.attach(P_SERVO_L);
    servo_r.attach(P_SERVO_R);
    stop();
    // make the Bluetooth Module reset
    pinMode(P_BT_RST, OUTPUT);
    digitalWrite(P_BT_RST, LOW);
    delay(100);
    digitalWrite(P_BT_RST, HIGH);
    delay(500);
}
// loop
void loop() { 
    // command recieve
    char c; 
    if( Serial.available() ) {
        c = Serial.read();
        command( c );
    }
    if( softSerial.available() ) {
        c = softSerial.read();
        command( c );
    }
    // LED
    cnt ++;
    if (cnt>10) {
        cnt = 0;
        if ( isBlink ) {
            digitalWrite(P_LED, isLed); 
            isLed = !isLed;
        }       
    }
    delay(100);
}
// command
void command( int c ) { 
    if ( c == '0' ) {
        // LED off
        isBlink = false;
        digitalWrite(P_LED, LOW); 
        Serial.println("LED off"); 
    } else if ( c == '1' ) {
        // LED on
        isBlink = false;
        digitalWrite(P_LED, HIGH); 
        Serial.println("LED on"); 
    } else if ( c == '2' ) {
        // LED blink
        isBlink = true;
        Serial.println("LED blink"); 
    } else if ( c == 'f' ) {
        // forward
        servo_l.write(180);
        servo_r.write(0);
        Serial.println("forward"); 
    }  else if ( c == 'b' ) {
        // backward
        servo_l.write(0);
        servo_r.write(180);
        Serial.println("backward"); 
    }  else if ( c == 'r' ) {
        // right turn
        servo_l.write(180);
        servo_r.write(180);	
        Serial.println("right"); 
    } else if ( c == 'l' ) {
        // left turn
        servo_l.write(0);
        servo_r.write(0);	 	
        Serial.println("left"); 
    } else {
        // atop
        stop();
        Serial.println("stop"); 
    } 
}
// stop
void stop() { 
    servo_l.write(90);
    servo_r.write(90);
}

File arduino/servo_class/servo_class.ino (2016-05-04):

// Test for Continuous Rotation Servo
//   using Servo class
// 2016-04-20 K.OHWADA @ FabLab Kannai
// https://www.arduino.cc/en/Reference/ServoWrite
// On a continuous rotation servo,
// this will set the speed of the servo
// with 0 being full-speed in one direction, 
// 180 being full speed in the other, 
// and a value near 90 being no movement
#include <Servo.h>
Servo myservo;
int PIN = 13;
int speed = 180;
void setup() { 
	myservo.attach(PIN);
	myservo.write(speed);
} 
void loop() {
	// dummy
} 

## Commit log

2016-05-04 First Version
    [BallCaster-custom.stl]
2016-05-12 arduino servo
2016-05-18 Sumobot Web Sample
